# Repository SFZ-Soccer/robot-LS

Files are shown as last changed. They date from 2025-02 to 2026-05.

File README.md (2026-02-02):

# RoboCup Soccer Robot

Dieses Projekt (stand 12.01.2026) enthält die Software für unseren **Soccer RoboCup Robot**, entwickelt von unserem Team:

- **Simon** – Programmierer  
- **Luka** – Hardware

Der Roboter kann anhand von IR-Sensoren dem Ball folgen und über die Pixy2 Kamera Tore erkennen und ansteuern. Die Steuerung erfolgt über einen **MeAuriga Robotercontroller**.

---

## Inhaltsverzeichnis

- [Funktionen](#funktionen)  
- [Hardware](#hardware)  
- [Softwarestruktur](#softwarestruktur)
- [Nutzungsbedingungen](#nutzungsbedingungen)

---

## Funktionen

- **Ballverfolgung (IR-Sensoren)**:  
  12 IR-Sensoren (Pins 2–9, 30–33) erkennen den Ball. Der Roboter berechnet die X- und Y-Richtung und fährt entsprechend darauf zu.

- **Torverfolgung (Pixy2 Kamera)**:  
  Der Roboter erkennt Tore anhand der Farben **Gelb** (Signature 1) und **Blau** (Signature 2) und steuert das Tor direkt an.

- **Motorsteuerung**:  
  Zwei Encoder-gesteuerte Motoren (rechts: SLOT1, links: SLOT2) werden über PWM angesteuert.  

- **Lichtabhängige Modi**:  
  Ein LDR-Sensor entscheidet, ob der Roboter IR-Modus (Ballverfolgung) oder Tormodus (Pixy2) aktiviert.

- **Einfache Konfigurierbarkeit**:  
  Variablen für Drehgeschwindigkeit, Fahrgeschwindigkeit, Deadzones und Schwellwerte sind direkt im Code anpassbar.

---

## Hardware

- **MeAuriga Roboterboard**  
- **Pixy2 Kamera**  
- **12 IR-Sensoren**  
- **Encoder-Motoren (SLOT1 & SLOT2)**  
- **Lichtsensor (LDR)**  
- **Relais für Zusatzfunktionen**  
- **Taster für Start/Stopp und Farbmodus**

**Anschlussübersicht:**

| Komponente | Pin / Slot |
|---|---|
| Motor rechts | SLOT1 |
| Motor links | SLOT2 |
| IR-Sensoren | Pins 2–9, 30–33 |
| LDR | Pin 66 |
| Startknöpfe | A15 (grün), A9 (rot) |
| Farbmodus Switch  | A10 |
| Relais | Pin 41 |
| Pixy2 I2C | Standard I2C Pins |

---

## Softwarestruktur

Das Projekt besteht aus drei Hauptdateien:

### 1. `main.ino`

- Initialisiert die **Pixy2 Kamera**, die **IR-Sensoren** und die **Motoren**.  
- Liest den **Lichtwert** vom LDR aus und entscheidet zwischen IR- und Tormodus.  
- Enthält die Grundfunktion `move(int m1speed, int m2speed)` für die Motorsteuerung.  

```cpp
void loop() {
  lichtWert = analogRead(ldr_pin);

  if (lichtWert > ldr_schwelle) {
    irmove();
    Serial.println("IR");
  } else {
    tormove(1);
    Serial.println("TOR");
  }
}
```

### 2. `ir_sensors.ino`

Dieses Modul liest die **IR-Sensoren** ein und berechnet die Richtungsvektoren `powerX` und `powerY`.  
Die Funktion `driveToBall()` steuert die Motoren entsprechend zur Ballposition.

**Hauptfunktionen:**

- `get_irValue()` – Liest die Werte aller 12 IR-Sensoren ein.  
- `get_irX()` – Berechnet den X-Richtungsvektor aus den Sensorwerten.  
- `get_irY()` – Berechnet den Y-Richtungsvektor aus den Sensorwerten.  
- `irmove()` – Hauptfunktion für die Ballverfolgung; ruft die oben genannten Funktionen auf und steuert die Motoren.

```cpp
int irmove() {
    get_irValue();
    get_irX();
    get_irY();
    driveToBall(powerX, powerY);
    powerX = 0;
    powerY = 0;
    return 0;
}
```

### 3. `tor_tracking.ino`

Dieses Modul steuert die **Pixy2 Kamera** zur Torerkennung und sorgt dafür, dass der Roboter das Tor korrekt anfährt.  
Die Steuerung basiert auf der X-Position des Tors, die von der Kamera ermittelt wird.

**Hauptfunktionen:**

- `tormove(int torcolor)` – Hauptfunktion für die Toransteuerung.  
  - Parameter `torcolor`: 1 = Gelb, 2 = Blau  
  - Ruft die Funktionen `getTor(torcolor)` und `moveTor()` auf.

- `getTor(int torcolor)` – Liest die X-Position des Tors aus der Pixy2-Kamera aus:
  - Prüft alle erkannten Blöcke der entsprechenden Farbe
  - Speichert die X-Koordinate in der Variablen `torX`

- `moveTor()` – Steuert die Motoren abhängig von der Torposition:
  - Wenn `torX` innerhalb der Deadzone → geradeaus  
  - Wenn `torX` links von der Deadzone → Drehung nach links  
  - Wenn `torX` rechts von der Deadzone → Drehung nach rechts  

**Beispiel:**

```cpp
void tormove(int torcolor) { //1 = gelb; 2= blau
  getTor(torcolor);
  moveTor();
}

void getTor(int torcolor) {
  pixy.ccc.getBlocks();
  if(pixy.ccc.numBlocks) { 
    for (int i = 0; i < pixy.ccc.numBlocks; i++) {
      if ((torcolor == 1 && pixy.ccc.blocks[i].m_signature == 1) ||
          (torcolor == 2 && pixy.ccc.blocks[i].m_signature == 2)) {
        torX = pixy.ccc.blocks[i].m_x;
      }
    }
  }
}

void moveTor() {
  if(torX >= torDeadzoneMin && torX <= torDeadzoneMax) {
    move(Fahren,Fahren); // Geradeaus
  } else {
    if(torX <= torDeadzoneMin) {
      move(Drehen, Drehen * -1); // Links drehend
    }
    if(torX >= torDeadzoneMax) {
      move(Drehen * -1, Drehen); // Rechts drehend
    }
  }
}
```
**Erklärung:**

- **tormove(int torcolor)**  
  Diese Funktion ist der Einstieg für die Toransteuerung. Sie entscheidet anhand der übergebenen Farbe (`1 = Gelb`, `2 = Blau`), welche Blöcke von der Pixy2-Kamera berücksichtigt werden. Anschließend ruft sie `moveTor()` auf, um die Motoren entsprechend zu steuern.

- **getTor(int torcolor)**  
  Liest die Blöcke, die von der Pixy2-Kamera erkannt werden, aus.  
  - Filtert nach der gewünschten Farbe (Torfarbe).  
  - Speichert die X-Position des erkannten Tors in der Variablen `torX`.  
  - Diese X-Position wird als Grundlage für die Steuerung genutzt.

- **moveTor()**  
  Steuert die Motoren abhängig von der Position des Tors (`torX`):  
  - **Innerhalb der Deadzone** → Motoren fahren **geradeaus**.  
  - **Links von der Deadzone** → Dreht den Roboter nach **links**.  
  - **Rechts von der Deadzone** → Dreht den Roboter nach **rechts**.  

- **Variablen und Konstanten**:  
  - `Fahren` – Geschwindigkeit für geradeaus fahren.  
  - `Drehen` – Geschwindigkeit für Drehungen.  
  - `torDeadzoneMin` / `torDeadzoneMax` – Definieren die horizontale Toleranz für die Geradeausbewegung.  
  - `move(int m1speed, int m2speed)` – Funktion zum direkten Ansteuern der Motoren.  

**Hinweis:**  
Die Pixy2-Kamera liefert kontinuierlich Blockdaten. Das Modul prüft in jedem Durchlauf, ob ein passender Block erkannt wurde, und passt die Fahrtrichtung des Roboters dynamisch an.

# Nutzungsbedingungen

Dieses Dokument beschreibt die Nutzungsbedingungen dieses Projekts
abhängig von der jeweiligen Version.

##  Nutzungsbedingungen nach Version

###  Version 1 (V1)

Version 1 dieses Projekts ist **frei nutzbar**.

Für V1 gilt:
- ✅ Private und kommerzielle Nutzung erlaubt
- ✅ Nutzung für Wettbewerbe (inkl. RoboCup) erlaubt
- ✅ Code darf kopiert, verändert und weiterverwendet werden
- ✅ Nutzung als Grundlage für eigene Projekte erlaubt

> Kurz gesagt: **Mit Version 1 darf alles gemacht werden.**

---

###  Version 2 (V2)

Version 2 unterliegt **eingeschränkten Nutzungsbedingungen**.

Für V2 gilt:
- ❌ Der Code darf **nicht kopiert** oder direkt übernommen werden
- ❌ Der Code darf **nicht für RoboCup oder andere Wettbewerbe** verwendet werden
- ✅ Private Nutzung ist erlaubt
- ✅ Der Code darf **als Inspiration oder Lernhilfe** für einen eigenen RoboCup-Roboter verwendet werden  
  (keine direkte Übernahme von Code, Modulen oder Algorithmen)

Bei Verstößen gegen diese Nutzungsbedingungen behält sich der Projektinhaber
entsprechende Schritte vor.

---

Vielen Dank für die faire Nutzung dieses Projekts 🙌
Eurer Team 
Luka & Simon

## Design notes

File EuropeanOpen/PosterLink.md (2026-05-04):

--> jeder der Zugriff auf diesen Link hat kann das Poster bearbeiten und speicher

[Poster - Link , bearbeiten/anschauen](https://canva.link/2tbrhdv00txoec2)

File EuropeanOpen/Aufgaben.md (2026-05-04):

# Aufgaben
## Poster
Allgemeine Aufgaben die dann übernommen werden können von Luka/Simon.

- [ ] Poster
  - [x] Programm aussuchen
  - [x] Format auswählen
  - [ ] Allgemeine Struktur
    - [x] Überschrift Name
    - [x] Flagge DE
    - [x] Bild
    - [ ] Design
    - [ ] Plätze für Unterkategorien  
  - [ ] Hardware
    - [ ] Grundsätzlicher Aufbau
  - [ ] Software
    - [ ] Grundsätzlicher Aufbau
    - [ ] Struktur main
    - [ ] Struktur irmove
    - [ ] Struktur tormove
          
  ### Infos Poster (Veranstalter):
  1. Poster Size – at most A1 Size 70.7cm (28”) high x 100.0cm (40”) wide (landscape).

  2. Title / Identification – team name, region, sub-league.

  3. Abstract – A concise summary of the entire project. The abstract should summarize the critical elements of the poster, but should avoid repeating what is          stated   elsewhere in the poster.

  4. Method / Robot Production / Design – A description of the choices made during the robots’ production, including the  
     rationale underlying those choices. Production includes the design, construction, programming, component selection, and overall process. Teams should              indicate the programming language, sensors used, time and cost of development. Also to include a bill of materials for the major components.

  5. Data / Results / Discussion - The poster has details of the team’s development and testing of the robot including any relevant data and modifications made as      part of the robot’s creation.

  6. Photos / Images – All images, including graphics for styling, should either be original or available for non-commercial reuse with modification  
     as per thecreative commons license (http://creativecommons.org/). Any photo or image should be labeled and cited especially if not original.

  7. All information in the poster should be in English.

  Format (erlaubt):
  Seiten: 1   
  Programm: PowerPoint  
  Dateityp: .pptx
  Überschrift:  
          
## Programm
- [x] Bug fix das das Programm startet

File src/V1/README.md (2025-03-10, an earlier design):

# robot

Das Repository der Wangener Soccer Gruppe des SFZ.

## Programm

```mermaid
flowchart TB
    subgraph fahrZumBall
        direction TB
        d1(Drehen bis der Ball gefunden)
        d2(Vorwärts bis der Ball erreicht)
        d1 --> d2
    end
    subgraph fahrInsTor
        direction TB
        d3(Mit dem Ball zum Tor drehen)
        d4(In das Tor fahren)
        d3 --> d4
    end
    fahrZumBall --> fahrInsTor
```

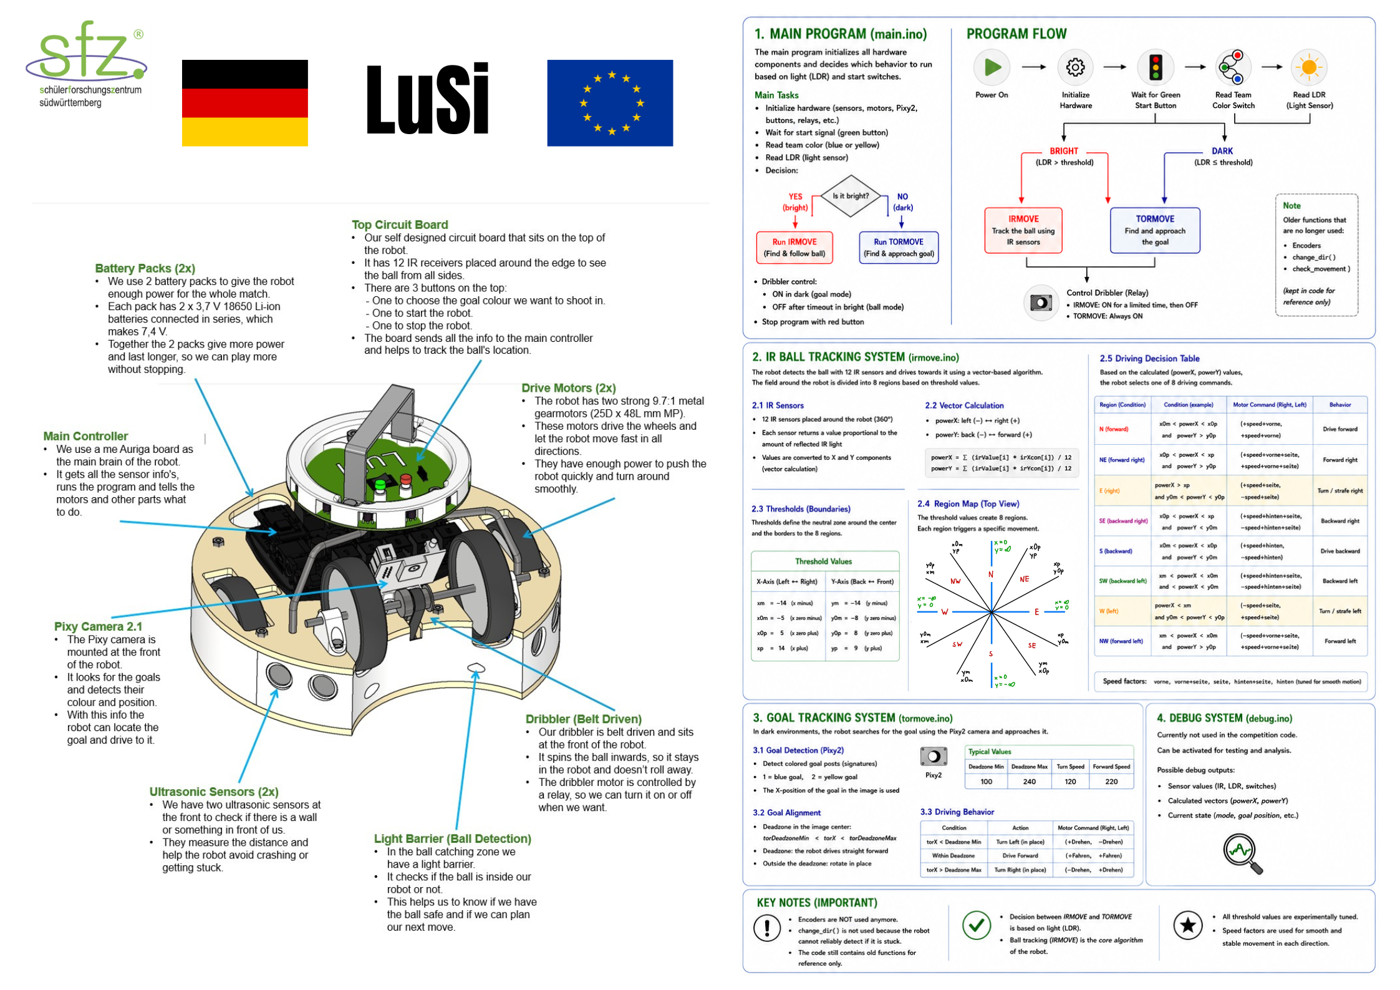
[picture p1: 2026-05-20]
EuropeanOpen/Lusi Poster.png

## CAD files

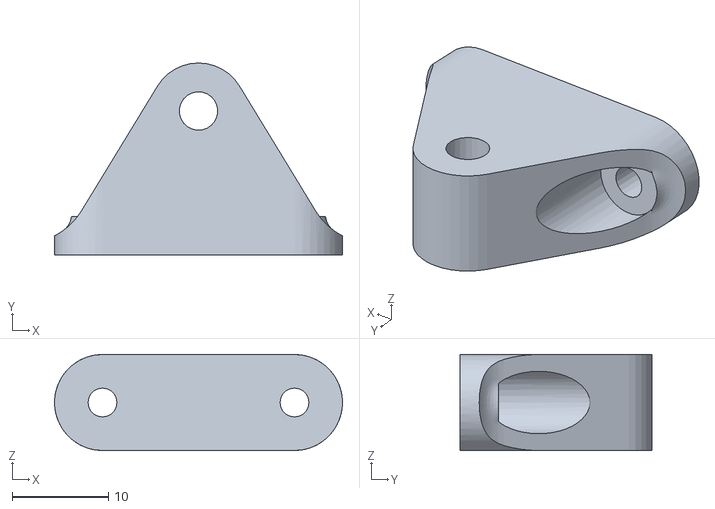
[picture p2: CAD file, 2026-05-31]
3D-Models/Wien 2026/stl files/holder dribbler bar.stl
30.0 x 20.0 x 10.0

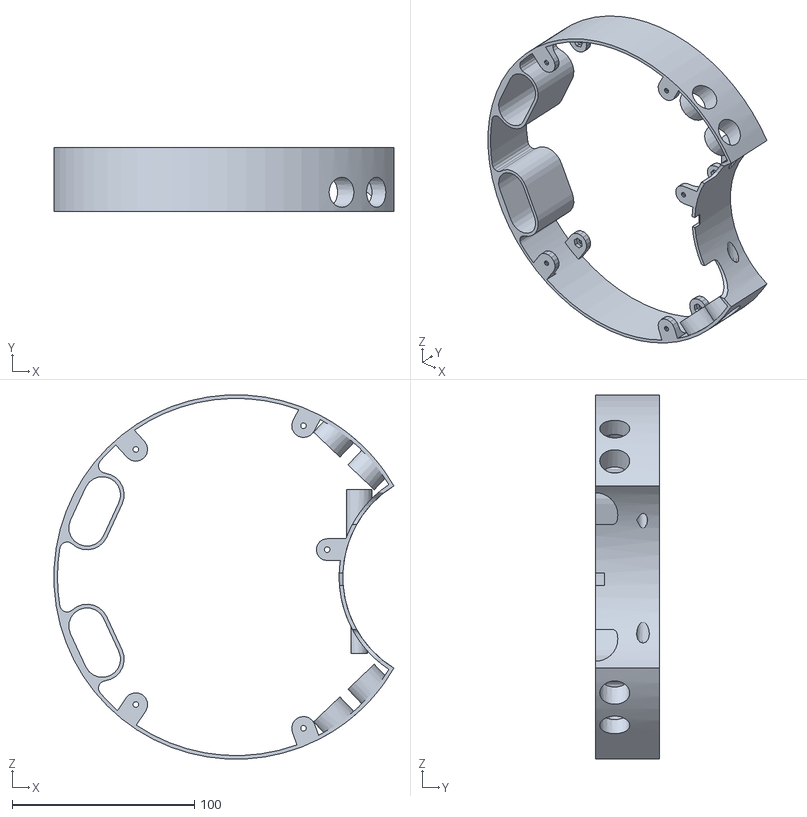
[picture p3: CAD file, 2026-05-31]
3D-Models/Wien 2026/stl files/border.stl
186.5 x 35.0 x 199.7

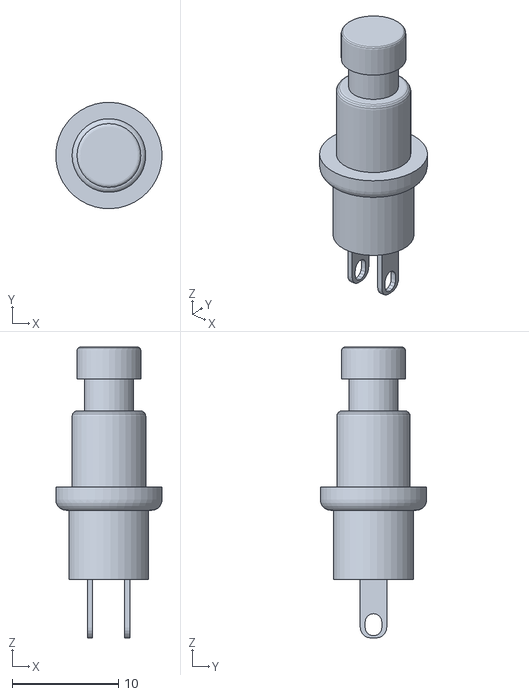
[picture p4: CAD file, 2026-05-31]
3D-Models/Wien 2026/stl files/button red.stl
9.99 x 9.99 x 27.3

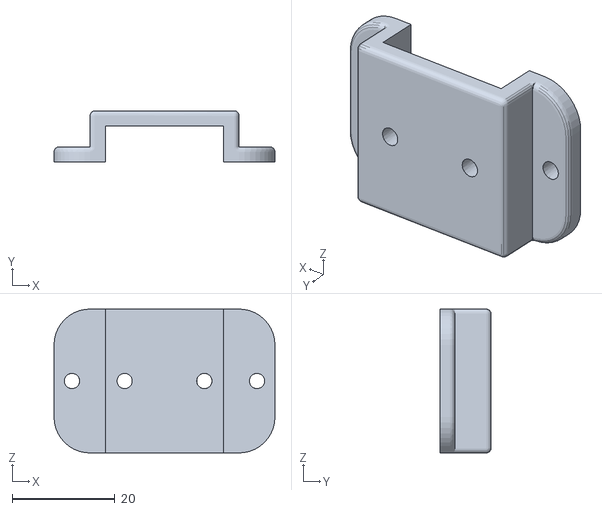
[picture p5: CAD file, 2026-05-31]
3D-Models/Wien 2026/stl files/ball bearing holder.stl
43.0 x 10.0 x 28.0

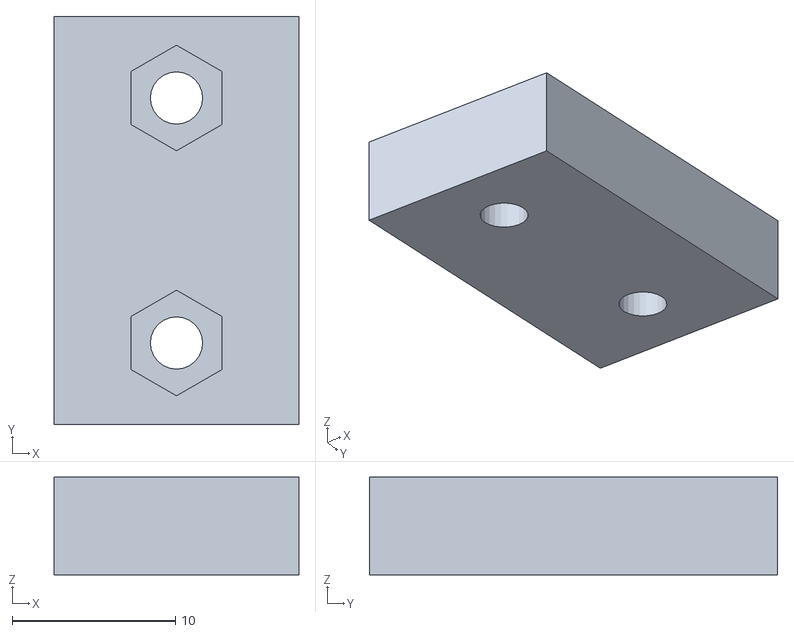
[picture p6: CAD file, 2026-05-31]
3D-Models/Wien 2026/stl files/Dribbler Motor Mount Upper Section.stl
15.0 x 25.0 x 6.00

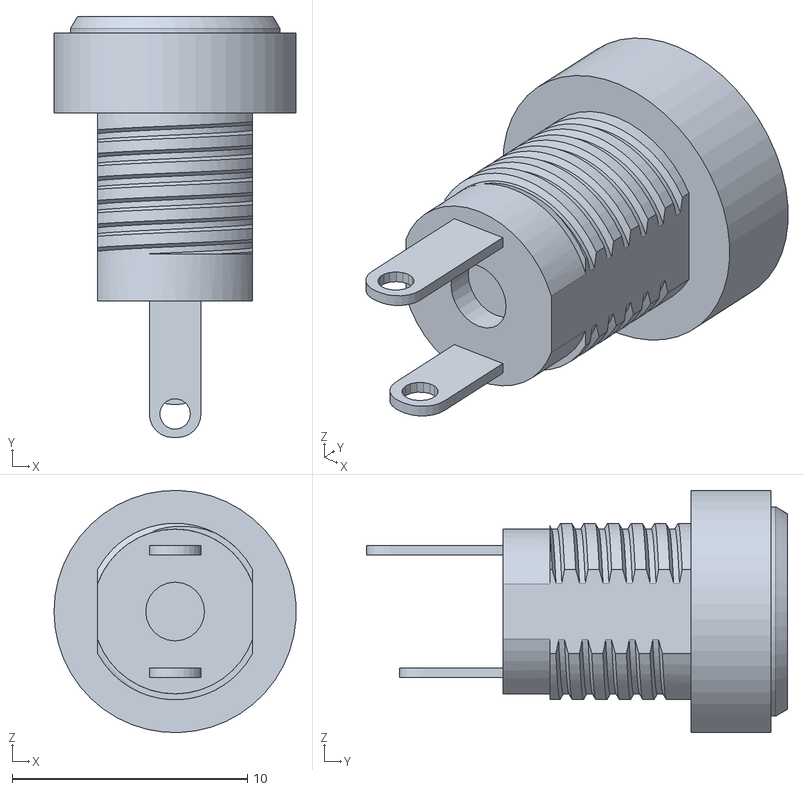
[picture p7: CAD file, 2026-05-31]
3D-Models/Wien 2026/stl files/battery socket.stl
10.3 x 17.9 x 10.3

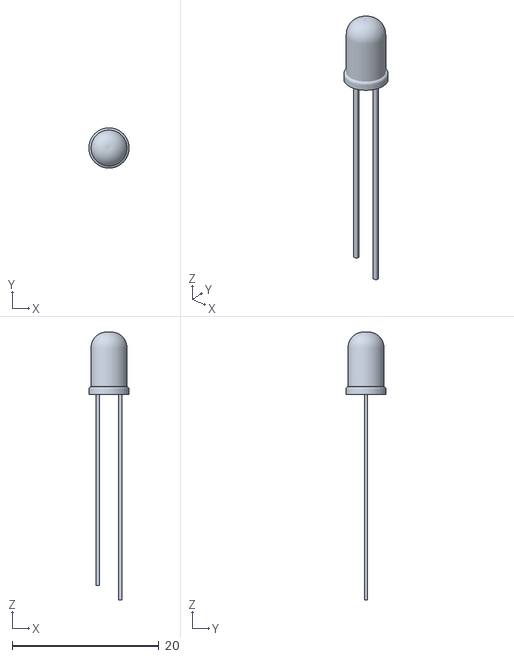
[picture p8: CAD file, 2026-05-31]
3D-Models/Wien 2026/stl files/blue led.stl
5.50 x 5.50 x 36.5

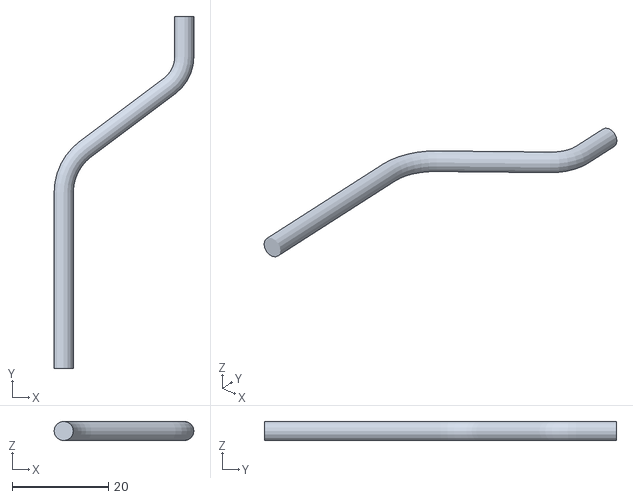
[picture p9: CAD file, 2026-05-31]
3D-Models/Wien 2026/stl files/rear iron bar.stl
29.0 x 73.0 x 4.00

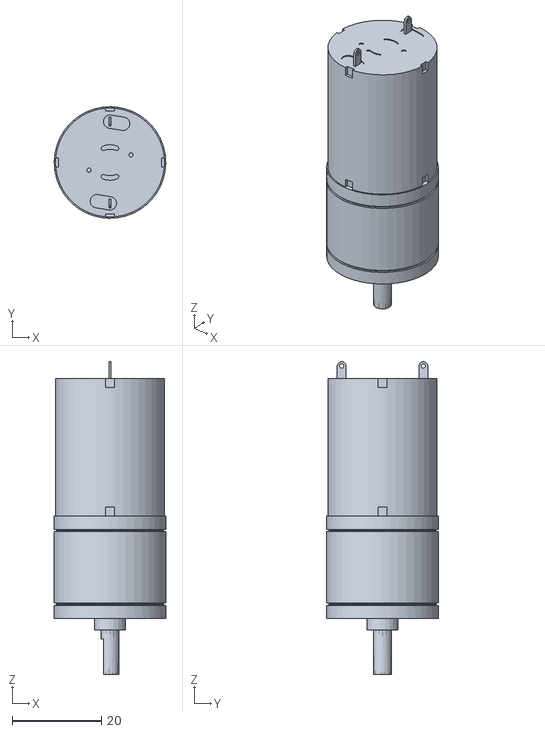
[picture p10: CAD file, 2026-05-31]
3D-Models/Wien 2026/stl files/drive motor.stl
25.0 x 25.0 x 70.1

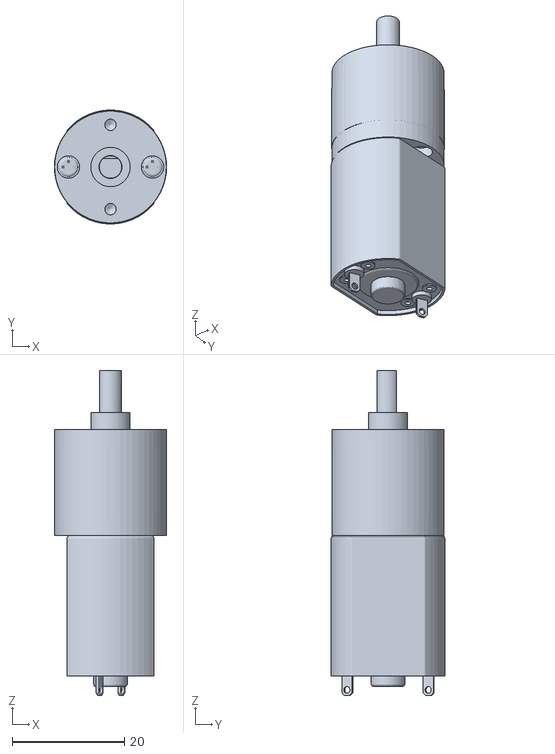
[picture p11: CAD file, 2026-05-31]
3D-Models/Wien 2026/stl files/Dribbler Motor.stl
20.0 x 20.3 x 57.9

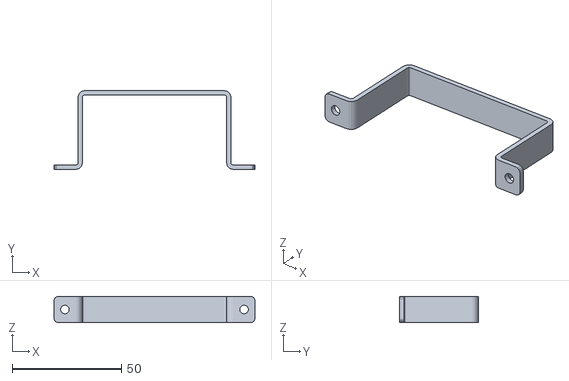
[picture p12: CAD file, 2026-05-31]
3D-Models/Wien 2026/stl files/handle.stl
92.0 x 36.0 x 12.0

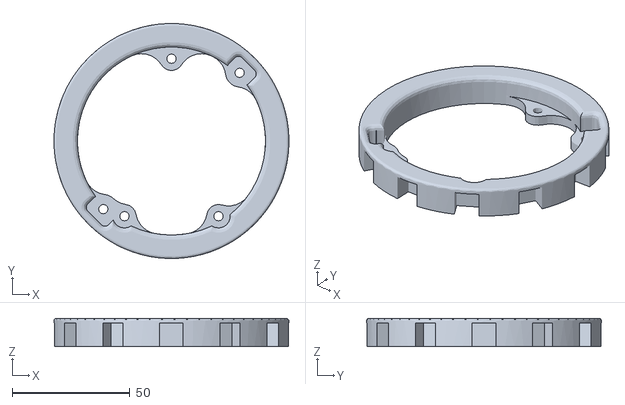
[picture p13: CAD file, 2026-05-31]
3D-Models/Wien 2026/stl files/IR-block.stl
100.0 x 100.0 x 12.0

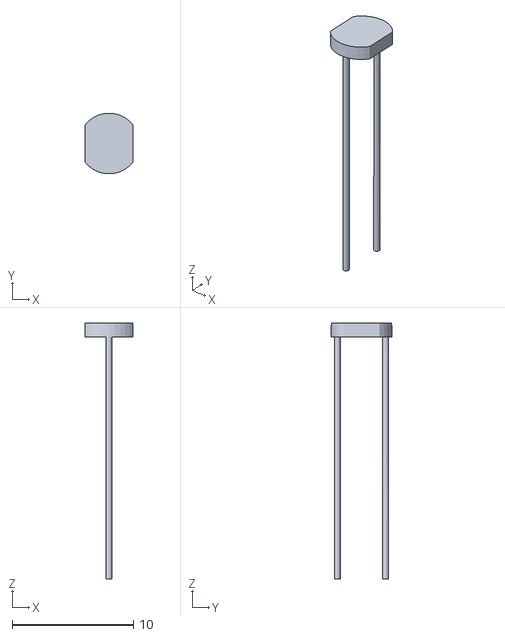
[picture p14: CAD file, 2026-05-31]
3D-Models/Wien 2026/stl files/LDR.stl
4.00 x 5.00 x 21.1

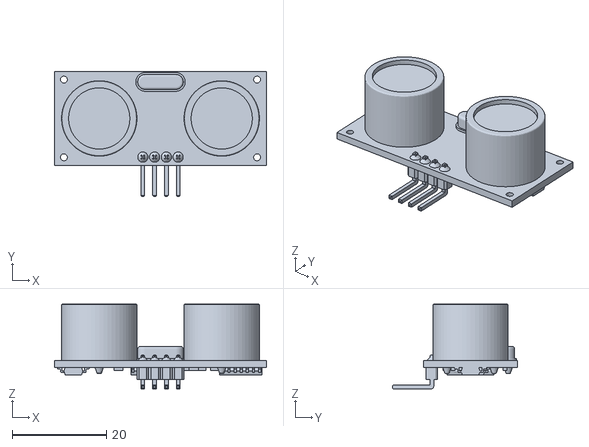
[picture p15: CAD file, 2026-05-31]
3D-Models/Wien 2026/stl files/ultrasonic sensor.stl
45.0 x 26.6 x 18.0

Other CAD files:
3D-Models/Wien 2026/stl files/button green.stl
3D-Models/Wien 2026/stl files/Pixy holder.stl
3D-Models/Wien 2026/stl files/front iron bar.stl
3D-Models/Wien 2026/stl files/IR-plate.stl
3D-Models/Wien 2026/main files/Dribbler Motor Mount Upper Section.ipt
3D-Models/Wien 2026/main files/Dribbler Motor.ipt
3D-Models/Wien 2026/main files/Dribbler motor mount lower section.ipt
3D-Models/Wien 2026/main files/IR-block.ipt
3D-Models/Wien 2026/main files/IR-plate.iam
3D-Models/Wien 2026/main files/LDR.ipt
3D-Models/Wien 2026/main files/Pixy cam.ipt
3D-Models/Wien 2026/main files/Pixy holder.ipt
3D-Models/Wien 2026/main files/Timing belt pulley.ipt
3D-Models/Wien 2026/main files/Timing belt.ipt
3D-Models/Wien 2026/main files/auriga board.ipt
3D-Models/Wien 2026/main files/ball bearing holder.ipt
3D-Models/Wien 2026/main files/ball bearing.ipt
3D-Models/Wien 2026/main files/base plate.ipt
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

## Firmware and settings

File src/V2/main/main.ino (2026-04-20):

#include <Arduino.h>
#include <MeAuriga.h>
#include <Pixy2.h>
#include <Wire.h>

#define relais_pin A11
#define ldr_pin 66
#define startswitch_pin_grun 44
#define startswitch_pin_rot 41 
#define colorswitch_pin 40

#define TRIG_PIN_links A13
#define ECHO_PIN_links A7
#define TRIG_PIN_rechts A8
#define ECHO_PIN_rechts A14

//------------------------------------------------------------------------------

//taktik

int ir_stillstand;
int tormove_stillstand;
unsigned long dirStartTime = 0;
int lastDir = -1;

unsigned long ir_stand_timer = 1000; // Schwellwert in ms


//main

float speedfaktor_l = 1; //0.95
float speedfaktor_r = 1;
bool program_run = false;
int lichtWert = 1000;
const int ldr_schwelle = 500; //alt: 970

static unsigned long dribblerTimer = 0;
static bool dribblerDelay = false;
static int dribbler_zeit = 1000; //Zeit wie lange der Dribbler noch an bleiben soll

//tormove

int torcolor; //1= blau; 2= gelb //signature

int torDeadzoneMin = 100; //200
int torDeadzoneMax = 240; //280
int Drehen = 120; //100 //70 //60
int Fahren = 220; //220 //170

//irmove 

Pixy2 pixy;

MeEncoderOnBoard m1(SLOT1); // rechts
MeEncoderOnBoard m2(SLOT2); // links

MeGyro gyro(0,0x69);

void move(int m1speed, int m2speed) { //ohne Encoder //rechts, links
  m1.setMotorPwm(m1speed * speedfaktor_r * -1);
  m2.setMotorPwm(m2speed * speedfaktor_l); 
}

int get_ultra_distance_links() { 
  digitalWrite(TRIG_PIN_links, LOW);
  delayMicroseconds(2);
  digitalWrite(TRIG_PIN_links, HIGH);
  delayMicroseconds(10);
  digitalWrite(TRIG_PIN_links, LOW);

  // Echo-Zeit messen
  long duration = pulseIn(ECHO_PIN_links, HIGH);

  // Entfernung berechnen
  float distance = (duration * 0.0343) / 2;
  /*
  Serial.print("Entfernung: ");
  Serial.print(distance);
  Serial.println(" cm");
  */

  return distance;
}

int get_ultra_distance_rechts() { 
  digitalWrite(TRIG_PIN_rechts, LOW);
  delayMicroseconds(2);
  digitalWrite(TRIG_PIN_rechts, HIGH);
  delayMicroseconds(10);
  digitalWrite(TRIG_PIN_rechts, LOW);

  // Echo-Zeit messen
  long duration = pulseIn(ECHO_PIN_rechts, HIGH);

  // Entfernung berechnen
  float distance = (duration * 0.0343) / 2;
  /*
  Serial.print("Entfernung: ");
  Serial.print(distance);
  Serial.println(" cm");
  */

  return distance;
}

void change_dir(int mode) {
  //move(rechts, links)
  if (mode == 1) { //fahre zu ultraschall größer
    if(get_ultra_distance_links() > get_ultra_distance_rechts()) {
      //drehung links
      move(-200,200);
      delay(600);
      Serial.print("XXXX");
    } else if(get_ultra_distance_rechts() > get_ultra_distance_links()) {
      //drehung rechts
      move(200,-200);
      delay(600);
      Serial.print("XXXX");
    }
  }

  if (mode == 2) { //
  
  }
}

void check_movement(int programmstatus) {
  //1=irmove
  //2=tormove
  if((m1.getCurrentSpeed() <= 3.00 || m2.getCurrentSpeed() <= 3.00) && (m1.getCurrentSpeed() >= -3.00 || m2.getCurrentSpeed() >= -3.00)) {
    change_dir(1);
  }
}

void isr_process_encoder1(void)
{
      if(digitalRead(m1.getPortB()) == 0){
            m1.pulsePosMinus();
      }else{
            m1.pulsePosPlus();
      }
}

void isr_process_encoder2(void)
{
      if(digitalRead(m2.getPortB()) == 0){
            m2.pulsePosMinus();
      }else{
            m2.pulsePosPlus();
      }
}


//--Setup und Loop--------------------------------------------------

void setup() {
  pixy.init();
  //gyro.update(); //ab hier muss der Roboter zum Tor stehen
  Serial.begin(9200);
  Serial.println("SETUP");
  pixy.setLamp(false, false);
  attachInterrupt(m1.getIntNum(), isr_process_encoder1, RISING);
  attachInterrupt(m2.getIntNum(), isr_process_encoder2, RISING);

  // Setze die Pins (2 bis 9, 30 bis 33) als Eingang für die IR-Sensoren
  for (int i = 2; i <= 9; i++) {
    pinMode(i, INPUT);
  }
  for (int i = 30; i <= 33; i++) {
    pinMode(i, INPUT);
  }

  pinMode(startswitch_pin_grun, INPUT_PULLUP); //Buttons als INPUT deffinieren
  pinMode(startswitch_pin_rot, INPUT_PULLUP);
  pinMode(colorswitch_pin, INPUT);
  pinMode(relais_pin, OUTPUT);
  pinMode(ldr_pin, INPUT);

  pinMode(TRIG_PIN_rechts, OUTPUT);
  pinMode(ECHO_PIN_rechts, INPUT);
  pinMode(TRIG_PIN_links, OUTPUT);
  pinMode(ECHO_PIN_links, INPUT);
}

void loop() {
  Serial.println("LOOP");
  move(0,0);

  if(digitalRead(startswitch_pin_grun) == 1) {
      program_run = true;
      Serial.println("RUN");
      if(digitalRead(colorswitch_pin) == 1) { //blau
        torcolor = 1;
      } else if (digitalRead(colorswitch_pin) == 0) {
        torcolor = 2;
      }
    } else if (digitalRead(startswitch_pin_rot) == 1) {
      program_run = false;
      analogWrite(relais_pin, 0); 
    }

  
  while(program_run == true) {
    _loop(); //für Encoder
    if(digitalRead(startswitch_pin_grun) == 1) {
      program_run = true;
    } else if (digitalRead(startswitch_pin_rot) == 1) {
      program_run = false;
      analogWrite(relais_pin, 0); 
    }

    lichtWert = analogRead(ldr_pin);

    if (lichtWert > ldr_schwelle) {
      irmove();
      Serial.println("IR");
      if (!dribblerDelay) {
        dribblerTimer = millis();
        dribblerDelay = true;
      }

      if (millis() - dribblerTimer >= dribbler_zeit) {
        analogWrite(relais_pin, 0);
      }

    } else {
      dribblerDelay = false;
      tormove(torcolor);
      Serial.println("TOR");
      analogWrite(relais_pin, 255);
    }
  }
}


void _loop() {
  m1.loop();
  m2.loop();
}

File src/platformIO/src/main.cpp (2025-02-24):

#include <Arduino.h>
#include <MeEncoderOnBoard.h>
#include <MeAuriga.h>
#include <Pixy2.h>

void isr_process_encoder1(void);
void isr_process_encoder2(void);
void detectedR();
void detectedL();
void move(int m1speed, int m2speed);
void dataoutput();
void getTor(int torcolor);
void moveTor();
void IRmove();

volatile unsigned long alteZeitR, alteZeitL, neueZeitR, neueZeitL, zeitLowR, zeitLowL, zeitHighR, zeitHighL, zeitHighRneu, zeitHighLneu, Ra, Rb, Rc, Rd, Re, La, Lb, Lc, Ld, Le, erg1, erg2;
int m1dataspeed, m2dataspeed;
int torDeadzoneMin = 120; // 200
int torDeadzoneMax = 220; // 280
int torX;
int width;
long stehzeit = 0;
int x;
int Entfernung_Ball = 7;
int Drehen = 75;  // 75
int Fahren = 170; // 170
const int wackelgrenze = 645;
bool startbutton_pressed = false;
MeEncoderOnBoard m1(SLOT1); // rechts
MeEncoderOnBoard m2(SLOT2); // links
MeUltrasonicSensor ultraSensor(PORT_7);
MePotentiometer potentiometer_6(8);
MeRGBLed rgb(0, 12);
Pixy2 pixy;

Me4Button btn(PORT_9);
uint8_t keyPressed = KEY_NULL;
uint8_t keyPressedPrevious = KEY_NULL;

//--------------------------------------------- Encoder init

void isr_process_encoder1(void)
{
  if (digitalRead(m1.getPortB()) == 0)
  {
    m1.pulsePosMinus();
  }
  else
  {
    m1.pulsePosPlus();
    ;
  }
}

void isr_process_encoder2(void)
{
  if (digitalRead(m2.getPortB()) == 0)
  {
    m2.pulsePosMinus();
  }
  else
  {
    m2.pulsePosPlus();
  }
}

//--------------------------------------------- IR Detection

void detectedR()
{
  neueZeitR = micros();
  if (digitalRead(3) == HIGH)
  {
    zeitHighR = neueZeitR - alteZeitR;
  }
  else
  {
    zeitLowR = neueZeitR - alteZeitR;
  }
  Ra = zeitHighR;
  Rb = zeitHighR;
  Rc = zeitHighR;
  Rd = zeitHighR;
  Re = zeitHighR;
  alteZeitR = neueZeitR;
}

void detectedL()
{
  neueZeitL = micros();
  if (digitalRead(2) == HIGH)
  {
    zeitHighL = neueZeitL - alteZeitL;
  }
  else
  {
    zeitLowL = neueZeitL - alteZeitL;
  }
  La = zeitHighL;
  Lb = zeitHighL;
  Lc = zeitHighL;
  Ld = zeitHighL;
  Le = zeitHighL;
  alteZeitL = neueZeitL;
}

//--------------------------------------------- MOVE

void move(int m1speed, int m2speed)
{
  m1.setMotorPwm(m1speed * -1);
  m2.setMotorPwm(m2speed);
  m1dataspeed = m1speed;
  m2dataspeed = m2speed;
}

//--------------------------------------------- DATA

void dataoutput()
{
  Serial.print("IR-L-High:");
  Serial.println(zeitHighLneu);

  Serial.print(" --- IR-L-Low:");
  Serial.println(zeitLowL);

  Serial.print("IR-R-High:");
  Serial.println(zeitHighRneu);

  Serial.print(" --- IR-R-Low:");
  Serial.println(zeitLowR);

  Serial.print("M1R:");
  Serial.println(m1dataspeed);

  Serial.print("M2L:");
  Serial.println(m2dataspeed);

  Serial.print("X-TOR:");
  Serial.println(torX);

  Serial.print("DeadzoneMax:");
  Serial.println(torDeadzoneMax);

  Serial.print("DeadzoneMin:");
  Serial.println(torDeadzoneMin);
}

//--------------------------------------------- TOR

void getTor(int torcolor)
{

  if (torcolor == 1)
  { // gelb
    pixy.ccc.getBlocks();
    // Wenn Blöcke erkannt wurden (mindestens ein Block)
    if (pixy.ccc.numBlocks)
    {
      // Gehe durch alle erkannten Blöcke
      for (int i = 0; i < pixy.ccc.numBlocks; i++)
      {
        // Hol die X- und Y-Koordinaten des Blocks
        if (pixy.ccc.blocks[i].m_signature == 1)
        {
          torX = pixy.ccc.blocks[i].m_x;
          // width = pixy.ccc.blocks[i].m_width;  // Breite des Blocks
          // torX = x + width / 2;
        }
      }
    }
  }
  else if (torcolor == 2)
  { // blau
    pixy.ccc.getBlocks();
    // Wenn Blöcke erkannt wurden (mindestens ein Block)
    if (pixy.ccc.numBlocks)
    {
      // Gehe durch alle erkannten Blöcke
      for (int i = 0; i < pixy.ccc.numBlocks; i++)
      {
        if (pixy.ccc.blocks[i].m_signature == 2)
        {
          torX = pixy.ccc.blocks[i].m_x;
          // width = pixy.ccc.blocks[i].m_width;  // Breite des Blocks
          // torX = x + width / 2;
        }
      }
    }
  }
}

void moveTor()
{
  // rgb.setColor(12,0,0,180); //grün
  // rgb.show();
  if (torX >= torDeadzoneMin && torX <= torDeadzoneMax)
  {
    // gerade aus
    move(Fahren, Fahren);
  }
  else
  {
    if (torX <= torDeadzoneMin)
    {
      //
      move(Drehen, Drehen * -1); // Panzerdrehung
    }
    if (torX >= torDeadzoneMax)
    {
      // rechts
      move(Drehen * -1, Drehen); // Panzerdrehung
    }
  }
}

//--------------------------------------------- IR MOVEMENT

void IRmove()
{
  if (abs(zeitHighLneu - zeitHighRneu) > 70)
  { // Sehr unterschiedliche Werte der Sensoren
    // rgb.setColor(12,0,180,0); //grün
    // rgb.show();
    if (zeitHighLneu >= zeitHighRneu)
    {
      // move(Drehen,0); //Normal
      rgb.setColor(4, 0, 50, 0); // grün
      rgb.show();
      move(Drehen, Drehen * -1); // Panzerdrehung
      rgb.setColor(4, 0, 0, 0);  // grün
      rgb.show();
    }
    else
    {
      // move(0,Drehen); //Normal
      rgb.setColor(8, 0, 50, 0); // grün
      rgb.show();
      move(Drehen * -1, Drehen); // Panzerdrehung
      rgb.setColor(8, 0, 0, 0);  // grün
      rgb.show();
    }
    //}
  }
  else
  {
    rgb.setColor(4, 0, 50, 0); // grün
    rgb.setColor(8, 0, 50, 0); // grün
    rgb.show();
    if (zeitHighLneu >= 100)
    {
      // rgb.setColor(12,180,0,0); //rot
      // rgb.show();
      move(Fahren, Fahren);
    }
    else
    {
      // rgb.setColor(6,180,0,0); //rot
      // rgb.show();
      move(Drehen, Drehen * -1);    // Panzerdrehung
      rgb.setColor(12, 50, 50, 50); // grün
    }
    rgb.setColor(4, 0, 0, 0); // grün
    rgb.setColor(8, 0, 0, 0); // grün
    rgb.show();
  }
}

//----------------------------------------------

void setup()
{
  rgb.setpin(44);
  Serial.begin(9600);
  pixy.init();
  rgb.setColor(0, 0, 0, 0); // grün
  rgb.show();
  attachInterrupt(digitalPinToInterrupt(3), detectedR, CHANGE);
  attachInterrupt(digitalPinToInterrupt(2), detectedL, CHANGE);

  attachInterrupt(m1.getIntNum(), isr_process_encoder1, RISING);
  attachInterrupt(m2.getIntNum(), isr_process_encoder2, RISING);
}
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

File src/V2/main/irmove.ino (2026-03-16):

#define NUM_SENSORS 12

int irDeadzoneMin_x = 120;
int irDeadzoneMax_x = 220;

const int xm = -14;
const int x0m = -5; //8
//0
const int x0p = 5;
const int xp = 14;

//---------------

const int ym = -14;
const int y0m = -8;
//0
const int y0p = 8;
const int yp = 9;

int speed = 408; //408 = 100% //alt:270

float vorne = 0.6;
float hinten = 0.5;
float vorneseite = 0.19;
float seite = 0.27;
float hintenseite = 0.4;

float irValue[NUM_SENSORS] = {0};

const float irYcon[NUM_SENSORS] = { 
    1.0000, 0.8660, 0.5000, 0.0000, -0.5000, -0.8660, 
   -1.0000, -0.8660, -0.5000, -0.0000,  0.5000,  0.8660 
};

const float irXcon[NUM_SENSORS] = { 
    0.0000,  0.5000,  0.8660,  1.0000,  0.8660,  0.5000, 
    0.0000, -0.5000, -0.8660, -1.0000, -0.8660, -0.5000 
};

long zeit, zeitA, zeitN;
long zeitH, zeitL;
long messungen, highs, lows, wechsel;
bool zustand;

float powerY = 0;
float powerX = 0;

// -------------------------------------------------

int irmove() {
    get_irValue();
    get_irX();
    get_irY();

    /*Serial.print("X:");
    Serial.print(powerX);
    Serial.print(",");
    Serial.print("Y:");
    Serial.println(powerY);*/

    driveToBall();

    powerX = 0;
    powerY = 0;

    return 0;
}

// -------------------------------------------------

void get_irValue() {

  // Pins 2–9
  for (int i = 2; i <= 9; i++) {

    zeitA = micros();
    zeitH = 0;
    zeitL = 0;
    wechsel = 0;

    zustand = digitalRead(i);
    unsigned long startZeit = micros();

    while (wechsel < 10 && micros() - startZeit < 3000) {
      if (zustand != digitalRead(i)) {
        zeitN = micros();
        if (zustand == HIGH) zeitL += zeitN - zeitA;
        else zeitH += zeitN - zeitA;

        zustand = !zustand;
        wechsel++;
        zeitA = zeitN;
      }
    }

    int sensorIndex = i - 2;
    irValue[sensorIndex] = zeitH / 13.0;
  }

  // Pins 30–33
  for (int i = 30; i <= 33; i++) {

    zeitA = micros();
    zeitH = 0;
    zeitL = 0;
    wechsel = 0;

    zustand = digitalRead(i);
    unsigned long startZeit = micros();

    while (wechsel < 10 && micros() - startZeit < 3000) {
      if (zustand != digitalRead(i)) {
        zeitN = micros();
        if (zustand == HIGH) zeitL += zeitN - zeitA;
        else zeitH += zeitN - zeitA;

        zustand = !zustand;
        wechsel++;
        zeitA = zeitN;
      }
    }

    int sensorIndex = (i - 30) + 8;
    irValue[sensorIndex] = zeitH / 13.0;
  }

  // Debug-Ausgabe für Serial Monitor
  /*
  for (int i = 0; i < NUM_SENSORS; i++) {
    Serial.print("Sensor ");
    Serial.print(i);
    Serial.print(": ");
    Serial.println(irValue[i]);
  }
  Serial.println("------------------------"); s
  */
}

// -------------------------------------------------

void get_irX() {
    for (int i = 0; i < NUM_SENSORS; i++) {
        powerX += irValue[i] * irXcon[i];
    }
    powerX = powerX / NUM_SENSORS;
}

void get_irY() {
    for (int i = 0; i < NUM_SENSORS; i++) {
        powerY += irValue[i] * irYcon[i];
    }
    powerY = powerY / NUM_SENSORS;
}

// -------------------------------------------------

void driveToBall() {
    //move(rechts,links)

    if(powerX < x0p && powerX > x0m && powerY > 0) { //N //y++ //x0 X
      //N
      move(speed *vorne,speed *vorne);
    }

    if(powerX < xp && powerX > x0p && powerY > 0) { //NO //y+ //x+ X
      //NO
      move(speed *vorneseite *-1,speed *vorneseite);
    }

    if(powerX > xp && powerY > y0m && powerY < y0p) { //O //y0 //x++ X
      //O
      move(speed *seite *-1, speed *seite);
    }

    if(powerX > x0p && powerX < xp && powerY < 0) {  //SO //y- //x+ X
      //SO
      move(speed *hintenseite *-1, speed *hintenseite);
    }

    if(powerX < x0p && powerX > x0m && powerY < 0) { //S //y-- //x0 X
      //S
      move(speed *hinten *-1, speed *hinten);
    }

    if(powerX < x0m && powerX > xm && powerY < 0) { //SW //y- //x-   X
      //SW
      move(speed *hintenseite, speed *hintenseite *-1);
    }

    if(powerX < xm && powerY > y0m && powerY < y0p) { //W //y0 //x-- X
      //W
      move(speed *seite, speed *seite *-1);
    }

    if(powerX < x0m && powerX > xm  && powerY > 0) { //NW //y+ //x- X
      //NW
      move(speed *vorneseite, speed *vorneseite *-1);
    }
}

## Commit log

2025-03-14 kein Dribbler am Board
2025-03-15 keine while schleifen und zurücksetzten verbessert
2025-03-24 versionen einteilung und neue programm einteilung
    [Arduino Mega 2560.ipt]
2025-04-28 IRScannenTest mit 12 Sensoren (funktioniert noch nicht)
2025-05-12 ir scannen Test mit 12 Sensoren
2025-05-12 einsetzen der ir scannen test
2025-07-14 encoder einbau versucht
2025-11-10 pixy wird nur noch in tormove benannt
2025-11-10 V3 in V2 kopiert und alte Dateien gelöscht
2025-11-24 Name geändert das die Variablen richtig deklariert werden
2025-12-15 idr sensor schleife hinz
2026-01-26 auswertung + motor_test
2026-02-23 num Sensors richtig geteilt
2026-02-26 Neue Ordner Strucktur bei Tests und IR_ScannenTest V2 hinz.
2026-03-02 Encoder Test hinzugefügt
2026-03-02 Ultraschall sensor funktion hinz. und taktikfunktion
2026-03-09 anpassung an neue Motoren
2026-03-13 dribbler timer hinzugefügt
2026-03-16 gyro_test hinzugefügt
2026-03-16 gyro hinz + port
2026-04-20 gyro update ausgeklammert bug fixed
    [main.ino]
2026-04-20 Create Aufgaben.md
    Aufgaben die noch bis zur EM gemacht werden müssen
2026-05-19 Create stl.
2026-05-19 Create stl files
